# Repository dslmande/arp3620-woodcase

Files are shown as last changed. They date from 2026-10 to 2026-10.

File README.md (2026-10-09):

# ARP 3620 replica — wooden case

Wooden enclosure for a DIY replica of the **ARP 3620** duophonic keyboard (the
keyboard of the ARP 2600P), built around a current **Fatar TP/9S 49-key** keybed
instead of the original ARP key mechanism.

Birch plywood covered in black tolex, with a removable lid. Everything is
generated from one parameter file: 3D model with collision checks, a DXF per
part, renders and a 10-sheet production drawing.

**Status: Rev0.1, design stage — not built yet.** Read the open points below
before cutting.

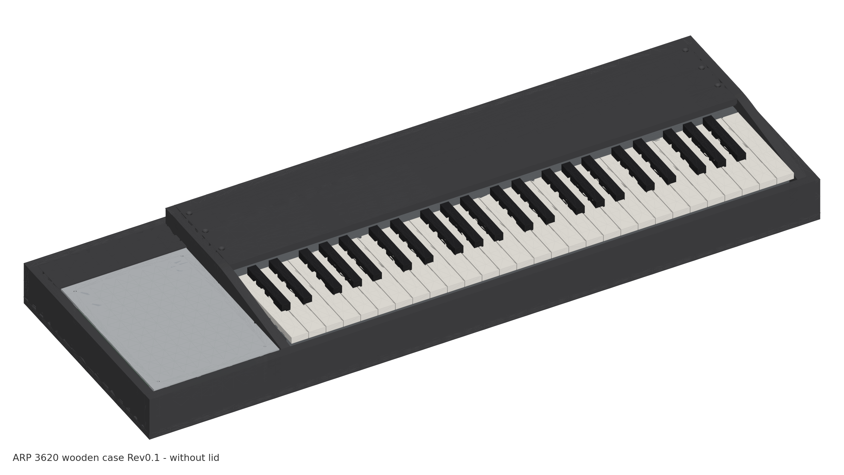
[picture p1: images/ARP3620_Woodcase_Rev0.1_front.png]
Case without lid


| | |
|---|---|
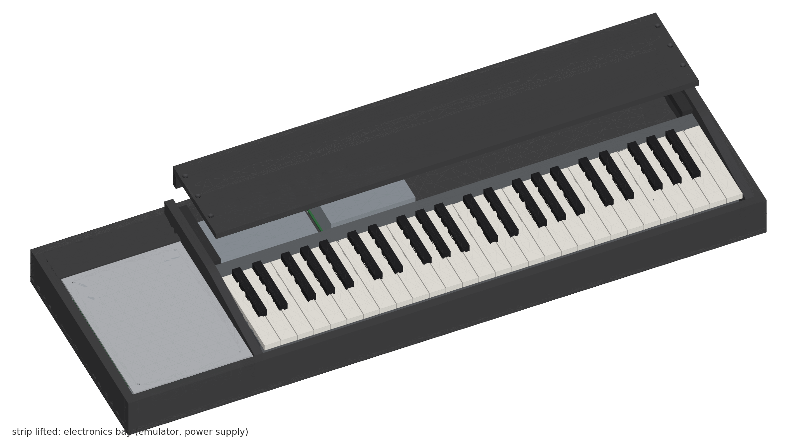
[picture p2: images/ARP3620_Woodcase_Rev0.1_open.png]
Electronics bay
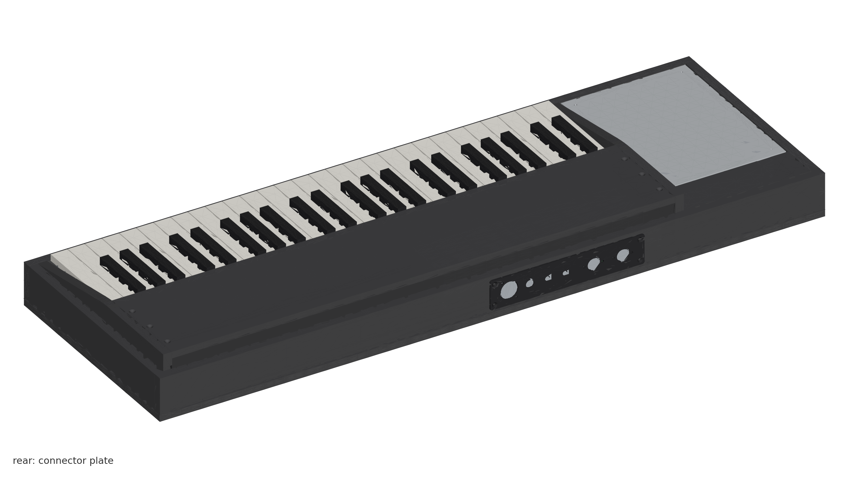
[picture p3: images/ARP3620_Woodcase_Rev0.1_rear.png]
Rear
|  |  |
| Strip lifted: electronics bay | Rear: connector plate |

## Concept

- **Layout as on the original and the 2014 clone:** control panel on the left,
  flush with the walls, keybed on the right between two cheeks, a raised strip
  behind the keys.
- **Heights follow from the keybed.** The keybed stands on two 12 mm risers so
  that the lower edge of the white key fronts sits just above the wall top. This
  leaves 48 mm under the control panel for the 3620 board.
- **Electronics bay behind the keybed**, under the removable strip: bus emulator
  (160 × 110) and power supply board (126 × 80). Cables to the panel section run
  through a notch in the left cheek.
- **Rear connector plate** (aluminium 2 mm) over a window in the rear wall: USB
  (option), DC IN, POWER, SUPPLY 2600/INT, MIDI IN, MIDI OUT. The connection to
  the ARP 2600 (6-pin GX16) sits on the control panel.
- **Lid** sits on the walls and is held by 4 draw latches; 30 mm clear height
  above the walls, 7 mm above the strip.

| | |
|---|---|
| Outside | 911 × 310 mm, walls 59 high, strip 82, with lid 95 (+ feet 12) |
| Material | birch plywood 12 / 9 / 6 mm, black tolex, aluminium rear plate |
| Mass | approx. 5.7 kg wood and plate (lid 1.6 kg), without keybed and electronics |
| Keybed | Fatar TP/9S 49 (683 × 161.5), screwed from below through base and risers |
| Control panel | 170 × 230 × 2 on four M3 standoffs from the base |

## Differences to the original 3620

- **Keys set back behind a front wall.** On the original the white keys reach
  almost to the front edge of the case (a top-view photo in the owner's manual
  shows only a 2–3 mm rim). Here the key fronts sit 15 mm behind the outer face
  (12 mm front wall + 3 mm clearance); the white key tops stand 9.5 mm above the
  wall. Kept on purpose (decision 09.10.2026).
- **Deeper case** (310 mm instead of roughly the panel depth of the original) for
  the electronics bay behind the keybed.

## Files

| Path | Content |
|---|---|
| [`production/ARP3620_Woodcase_Rev0.1_drawing.pdf`](production/ARP3620_Woodcase_Rev0.1_drawing.pdf) | Drawing, A3, 10 sheets: overview, general arrangement, sections, every part with dimensions and hole tables, cut list, hardware, assembly |
| [`production/dxf/`](production/dxf/) | One DXF (R12, mm) per distinct part, seen from its front face. Layers `OUTLINE`, `CUTOUT`, `DRILL`, `CSK_FRONT`, `CSK_BACK` (countersink on the far face), `PILOT`, `ENGRAVE` |
| [`production/ARP3620_Woodcase_Rev0.1.step`](production/ARP3620_Woodcase_Rev0.1.step) | All case parts as solids |
| `model/` | FreeCAD file, assembly STEP with simplified reference bodies (keybed, panel, boards), check report, DXF preview |
| `images/` | Renders |
| `scripts/` | Generator, see below |

## How the data are made

Nothing is drawn by hand. `scripts/params.py` holds every dimension,
`scripts/parts.py` describes each part as a flat outline with holes and
cut-outs. From that:

```bash
scripts/make.sh
```

runs `build.py` (FreeCAD: solids, collision and clearance checks, STEP),
`dxf_out.py` and `dxf_preview.py` (DXF, read back with an independent parser),
`render.py` and `drawing.py`. Needs FreeCAD 1.x (`freecadcmd`) and Python 3 with
matplotlib.

**Checked in the 3D model** (`model/check.txt`): every part is a valid solid,
90 part pairs without collision, and the clearances keybed–cheeks 3, keys–front
wall 3, panel all round 2, lid–strip 7, and electronics to strip, apron and rear
plate parts. Countersinks were verified to open to the intended face.

## Open points (check before cutting)

- **Key front height.** The lower edge of the white key fronts, 39 mm above the
  mounting plane, is scaled from the Fatar drawing. All case heights follow
  from it (`KB_LIP` in `params.py`). Measure it on the real keybed first.
- **Keybed screws.** The feet have 4.5 mm holes; screw type and length still to
  be confirmed on the keybed.
- **Space under the control panel.** The 12 mm board spacer and 25 mm for parts
  and plugs under the 3620 board are estimates. Check them with the built board.
- **Rear plate.** The hole sizes are placeholders until the sockets and
  switches are chosen.
- **Hardware.** Latch type, optional handle and case corners.

## Reference: the 2014 clone

The DIY clone from 2014 (Muffwiggler group buy) used a black MDF case,
915 × 257 mm, with a lid. Its drawings were made for a Kimber Allen keybed and
are **not part of this repository** — they are third-party work and stay with
their author. They are attached to the project page in the wiki:
[ARP 3620 Keyboard Clone](https://diysynth.wiki.dsl-man.de/wiki/spaces/DSO/pages/1146915).
This design takes only the overall concept from them; all dimensions are derived
anew from the Fatar keybed and the panel.

## License

© 2026 Dsl-man.de

Licensed under [Creative Commons Attribution-ShareAlike 4.0 International](LICENSE)
(CC BY-SA 4.0), including the generator scripts. You may build, modify and
redistribute this design, commercially too, as long as you credit the source and
share your changes under the same license.

Not covered by this license: third-party documents referred to above (the 2014
case drawings, the Fatar datasheet), which keep their own rights. The keybed
dimensions used here are taken from the Fatar TP/9S datasheet.

ARP and ARP 3620 are names of ARP Instruments, Inc. This is an independent
DIY project, not affiliated with or endorsed by ARP or its successors.

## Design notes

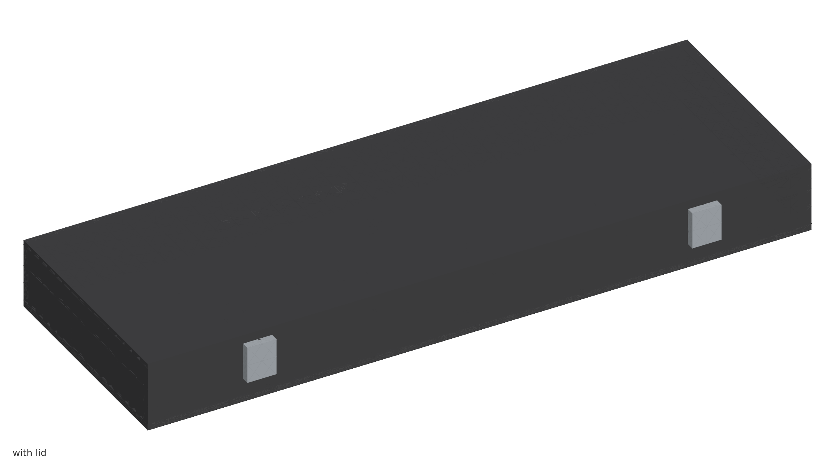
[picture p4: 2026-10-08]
images/ARP3620_Woodcase_Rev0.1_closed.png

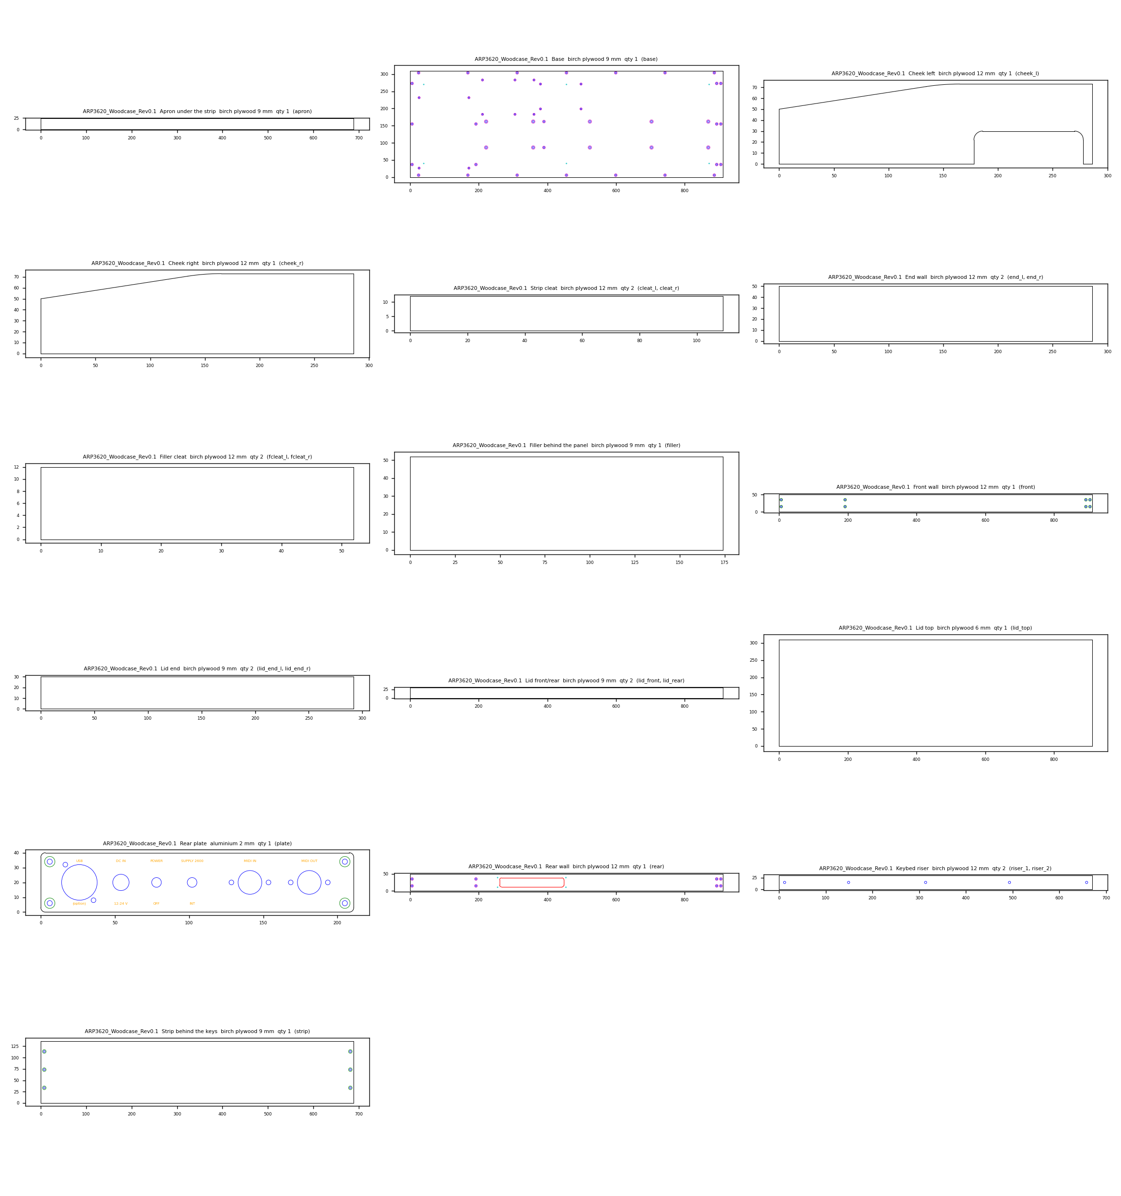
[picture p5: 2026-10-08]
model/dxf_preview.png

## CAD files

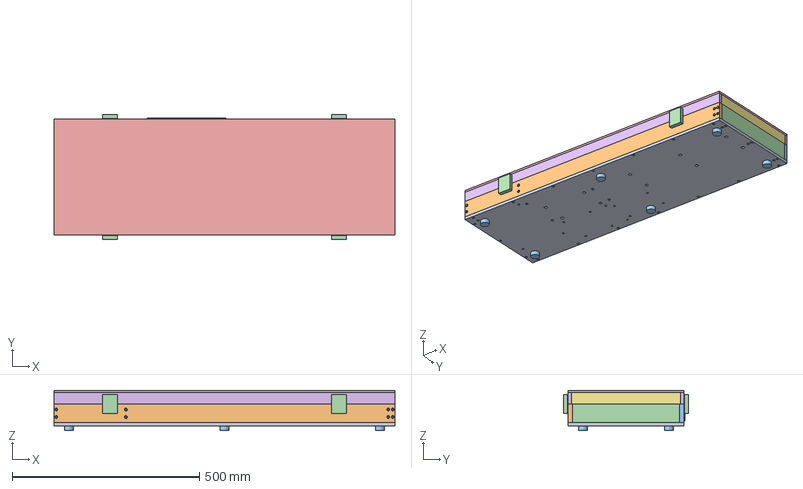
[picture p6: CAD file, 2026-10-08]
model/ARP3620_Woodcase_Rev0.1_assembly.step
911.0 x 334.0 x 107.0 mm
Base
Front wall
Rear wall
End wall
End wall001
Cheek left
Cheek right
Keybed riser
Keybed riser001
Strip behind the keys
Apron under the strip
Strip cleat
Strip cleat001
Filler behind the panel
Filler cleat
Filler cleat001
Lid top
Lid front/rear
Lid front/rear001
Lid end
Lid end001
Rear plate
REF keybed_frame
REF keys_white
REF keys_black
REF panel
REF panel_standoffs
REF board3620
REF board3620_parts
REF panel_jacks
REF emulator
REF emulator_parts
REF emulator_standoffs
REF psu
REF psu_parts
REF psu_standoffs
REF plate_parts
REF feet
REF latches

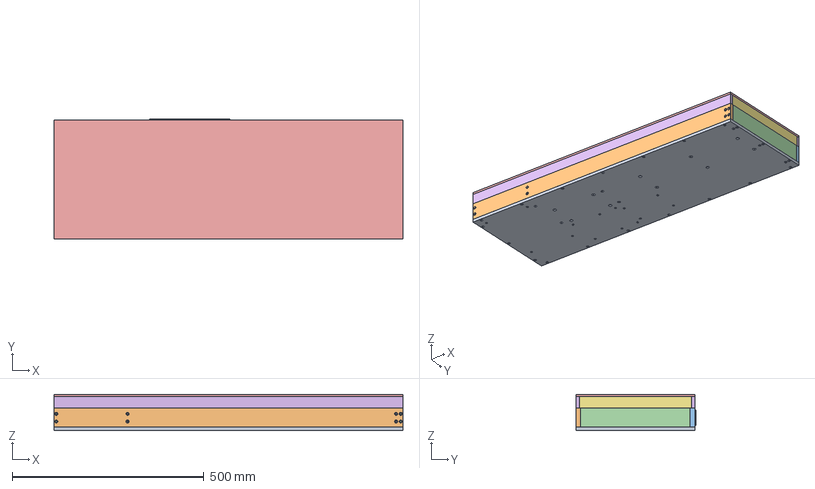
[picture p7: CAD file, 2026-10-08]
production/ARP3620_Woodcase_Rev0.1.step
911.0 x 313.0 x 95.0 mm
Base
Front wall
Rear wall
End wall
End wall001
Cheek left
Cheek right
Keybed riser
Keybed riser001
Strip behind the keys
Apron under the strip
Strip cleat
Strip cleat001
Filler behind the panel
Filler cleat
Filler cleat001
Lid top
Lid front/rear
Lid front/rear001
Lid end
Lid end001
Rear plate

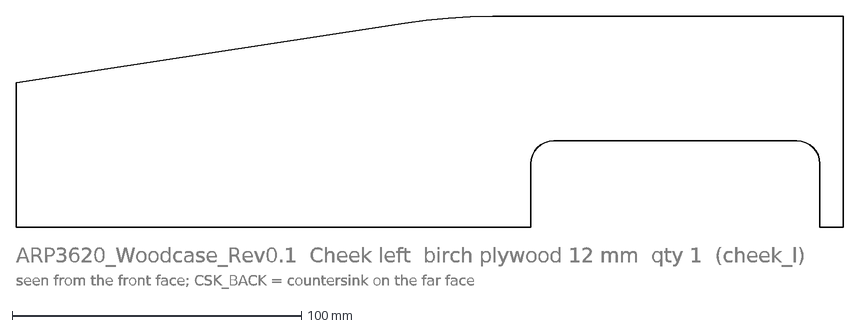
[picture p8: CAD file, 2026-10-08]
production/dxf/ARP3620_Woodcase_Rev0.1_cheek_l.dxf
ARP3620_Woodcase_Rev0.1 Cheek left birch plywood 12 mm qty 1 (cheek_l)
seen from the front face; CSK_BACK = countersink on the far face

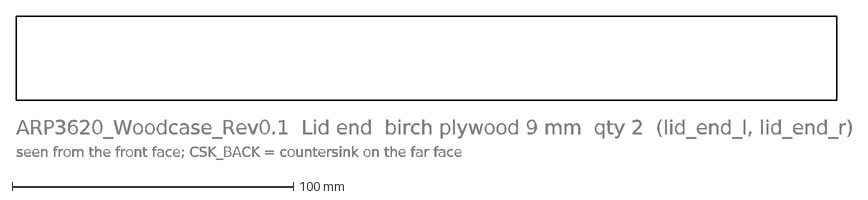
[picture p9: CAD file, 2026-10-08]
production/dxf/ARP3620_Woodcase_Rev0.1_lid_end_l.dxf
ARP3620_Woodcase_Rev0.1 Lid end birch plywood 9 mm qty 2 (lid_end_l, lid_end_r)
seen from the front face; CSK_BACK = countersink on the far face

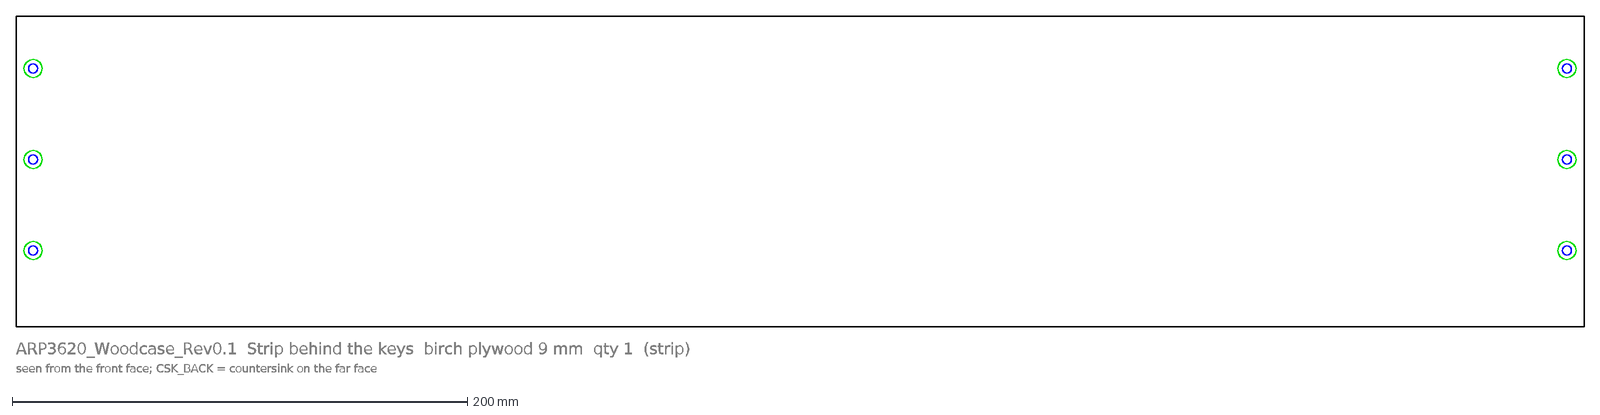
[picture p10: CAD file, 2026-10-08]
production/dxf/ARP3620_Woodcase_Rev0.1_strip.dxf
ARP3620_Woodcase_Rev0.1 Strip behind the keys birch plywood 9 mm qty 1 (strip)
seen from the front face; CSK_BACK = countersink on the far face

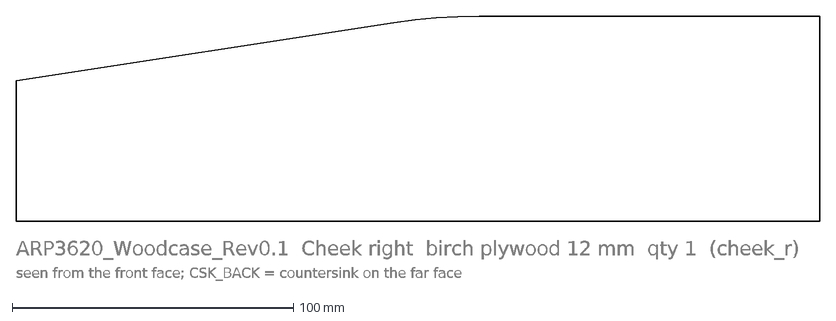
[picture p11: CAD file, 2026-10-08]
production/dxf/ARP3620_Woodcase_Rev0.1_cheek_r.dxf
ARP3620_Woodcase_Rev0.1 Cheek right birch plywood 12 mm qty 1 (cheek_r)
seen from the front face; CSK_BACK = countersink on the far face

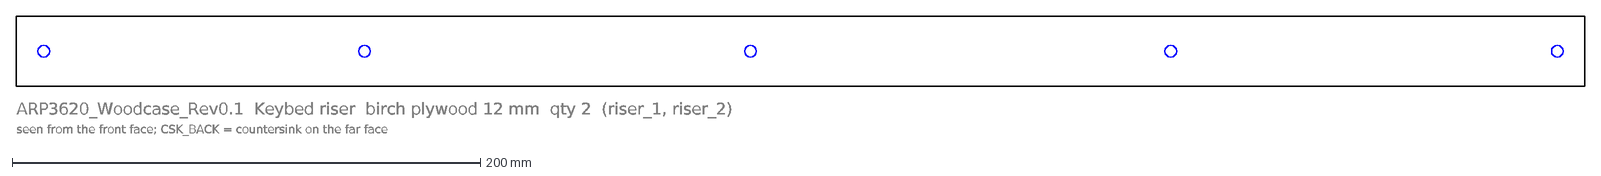
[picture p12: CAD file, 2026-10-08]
production/dxf/ARP3620_Woodcase_Rev0.1_riser_1.dxf
ARP3620_Woodcase_Rev0.1 Keybed riser birch plywood 12 mm qty 2 (riser_1, riser_2)
seen from the front face; CSK_BACK = countersink on the far face

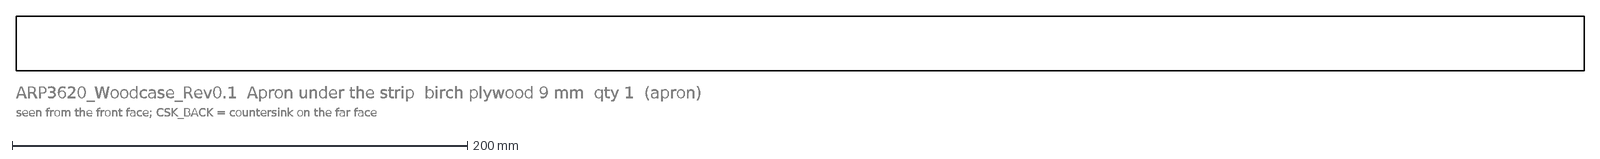
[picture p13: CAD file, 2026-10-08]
production/dxf/ARP3620_Woodcase_Rev0.1_apron.dxf
ARP3620_Woodcase_Rev0.1 Apron under the strip birch plywood 9 mm qty 1 (apron)
seen from the front face; CSK_BACK = countersink on the far face

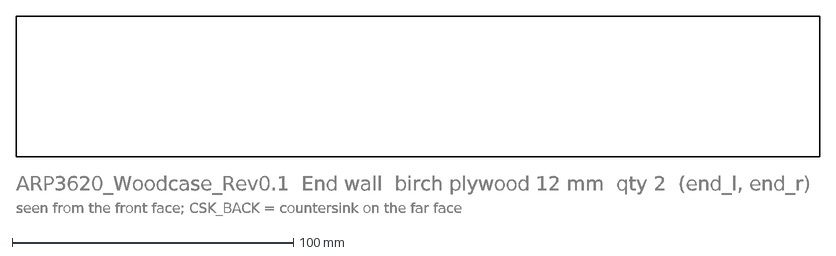
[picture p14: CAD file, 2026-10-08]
production/dxf/ARP3620_Woodcase_Rev0.1_end_l.dxf
ARP3620_Woodcase_Rev0.1 End wall birch plywood 12 mm qty 2 (end_l, end_r)
seen from the front face; CSK_BACK = countersink on the far face

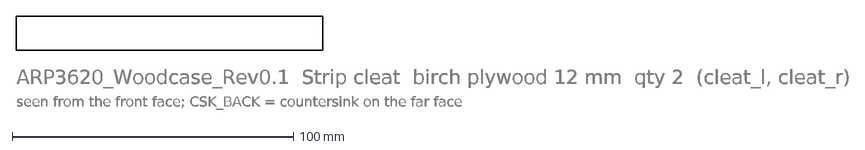
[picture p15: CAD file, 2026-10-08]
production/dxf/ARP3620_Woodcase_Rev0.1_cleat_l.dxf
ARP3620_Woodcase_Rev0.1 Strip cleat birch plywood 12 mm qty 2 (cleat_l, cleat_r)
seen from the front face; CSK_BACK = countersink on the far face

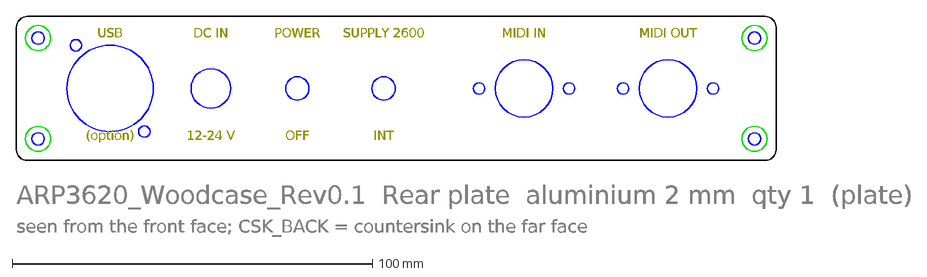
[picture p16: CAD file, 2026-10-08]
production/dxf/ARP3620_Woodcase_Rev0.1_plate.dxf
USB
(option)
DC IN
12-24 V
POWER
OFF
SUPPLY 2600
INT
MIDI IN
MIDI OUT
ARP3620_Woodcase_Rev0.1 Rear plate aluminium 2 mm qty 1 (plate)
seen from the front face; CSK_BACK = countersink on the far face

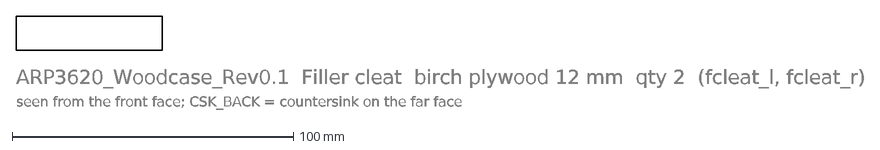
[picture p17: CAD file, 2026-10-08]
production/dxf/ARP3620_Woodcase_Rev0.1_fcleat_l.dxf
ARP3620_Woodcase_Rev0.1 Filler cleat birch plywood 12 mm qty 2 (fcleat_l, fcleat_r)
seen from the front face; CSK_BACK = countersink on the far face

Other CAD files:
model/ARP3620_Woodcase_Rev0.1.FCStd
production/dxf/ARP3620_Woodcase_Rev0.1_lid_front.dxf
production/dxf/ARP3620_Woodcase_Rev0.1_base.dxf
production/dxf/ARP3620_Woodcase_Rev0.1_front.dxf
production/dxf/ARP3620_Woodcase_Rev0.1_rear.dxf
production/dxf/ARP3620_Woodcase_Rev0.1_lid_top.dxf
production/dxf/ARP3620_Woodcase_Rev0.1_filler.dxf

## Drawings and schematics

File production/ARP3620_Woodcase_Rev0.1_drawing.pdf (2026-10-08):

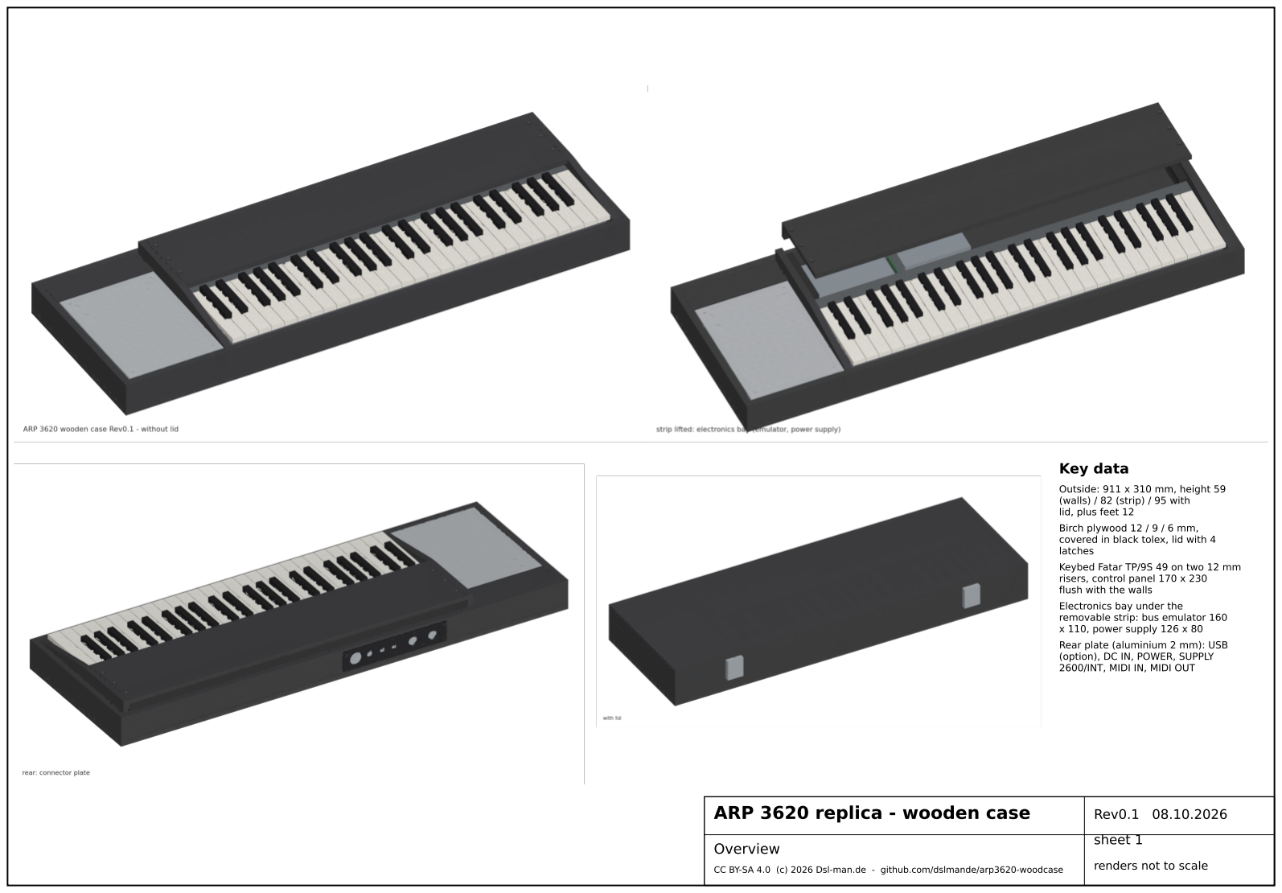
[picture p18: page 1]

ARP 3620 replica - wooden case | Rev0.1 08.10.2026
Overview CC BY-SA 4.0 (c) 2026 Dsl-man.de - github.com/dslmande/arp3620-woodcase | sheet 1 renders not to scale

## Key data

Outside: 911 x 310 mm, height 59 (walls) / 82 (strip) / 95 with
lid, plus feet 12

Birch plywood 12 / 9 / 6 mm, covered in black tolex, lid with 4 latches

Keybed Fatar TP/9S 49 on two 12 mm risers, control panel 170 x 230
flush with the walls

Electronics bay under the
removable strip: bus emulator 160 x 110, power supply 126 x 80

Rear plate (aluminium 2 mm): USB (option), DC IN, POWER, SUPPLY 2600/INT, MIDI IN, MIDI OUT

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

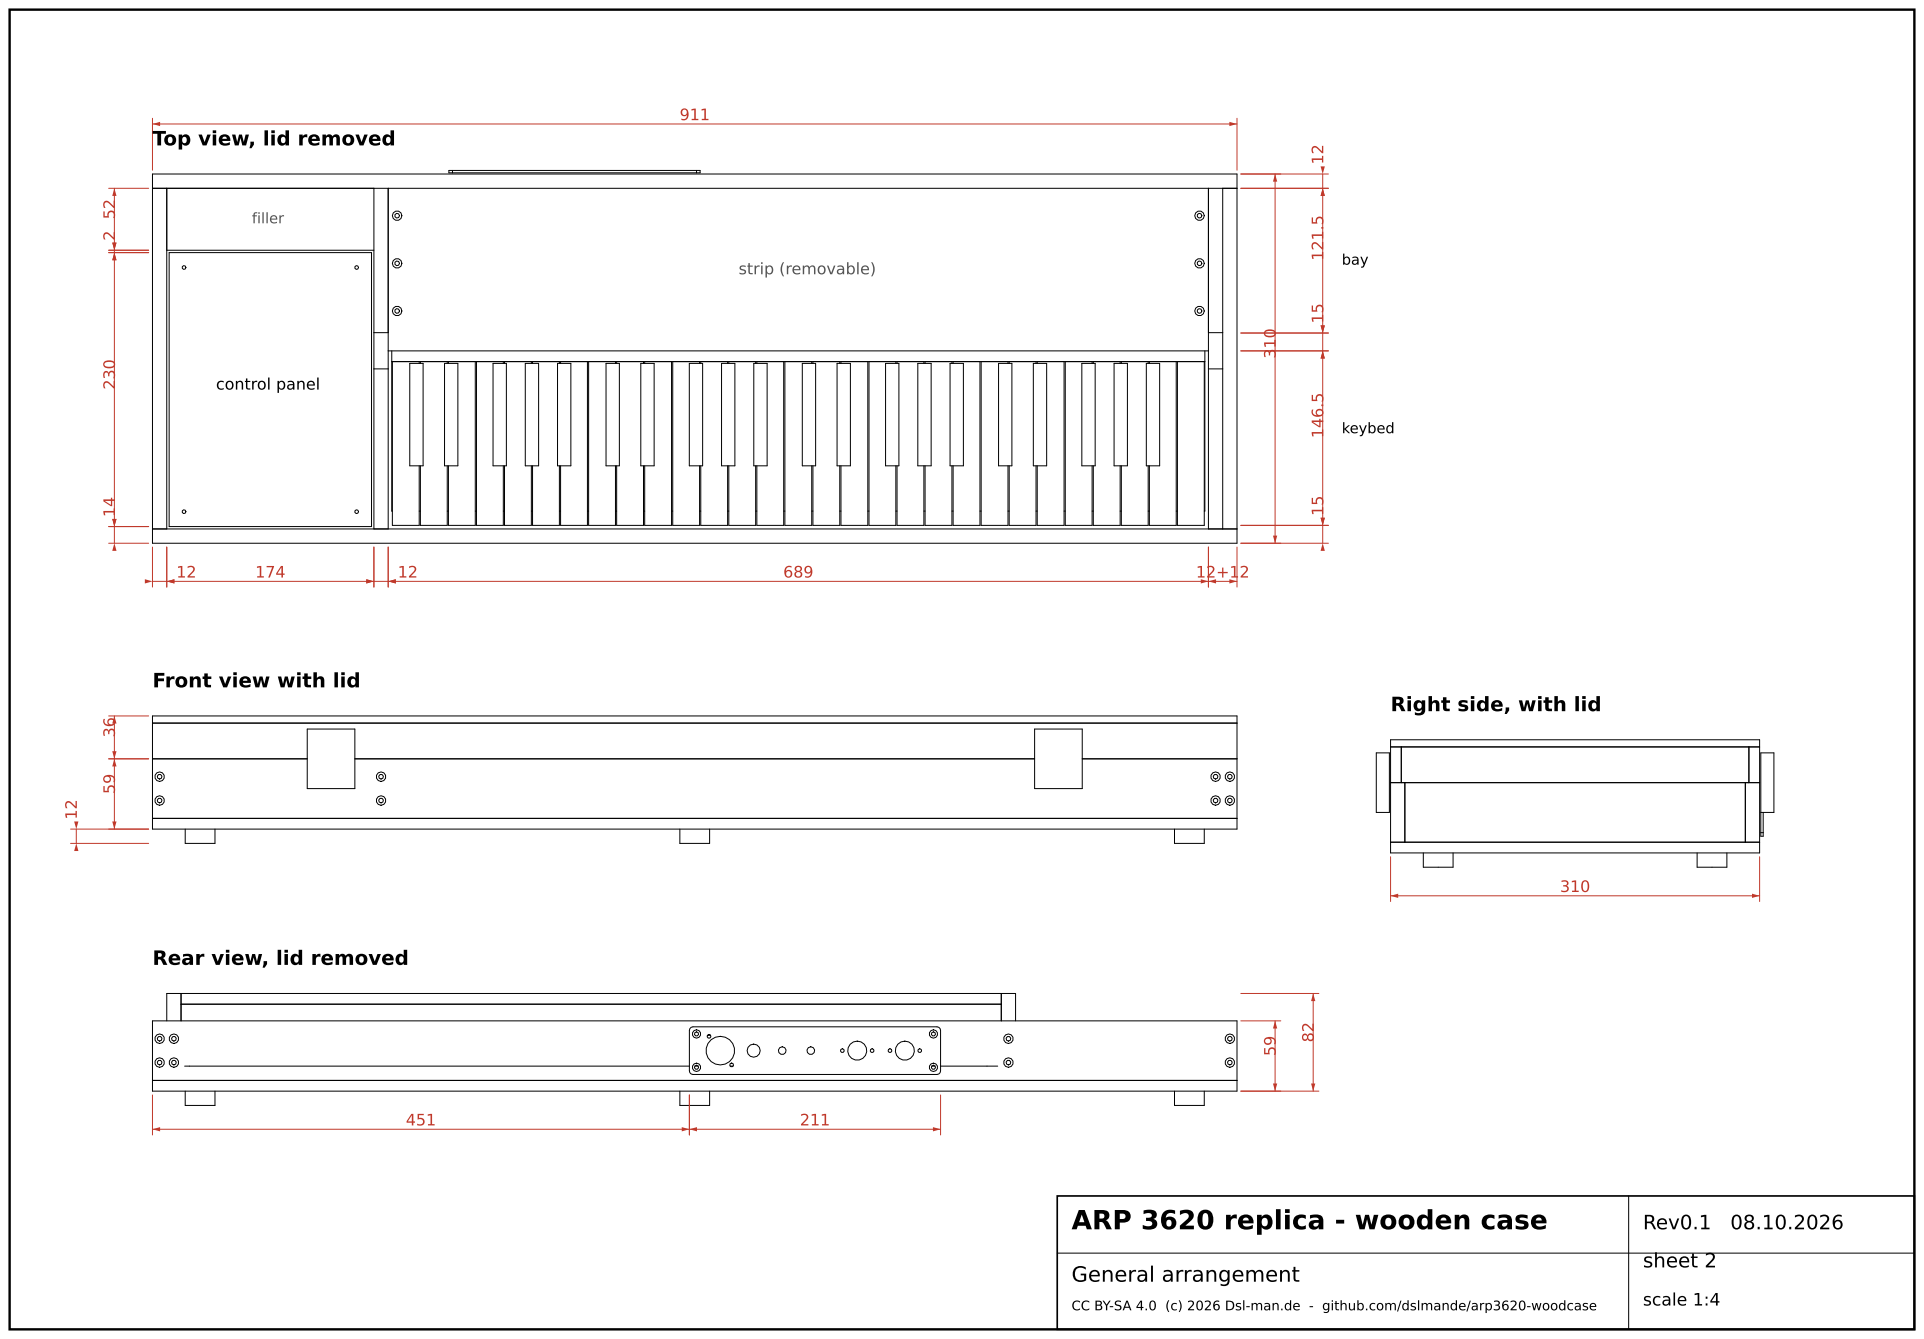
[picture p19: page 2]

## Section A-A at x = 440 (keyboard, power supply), seen from the right

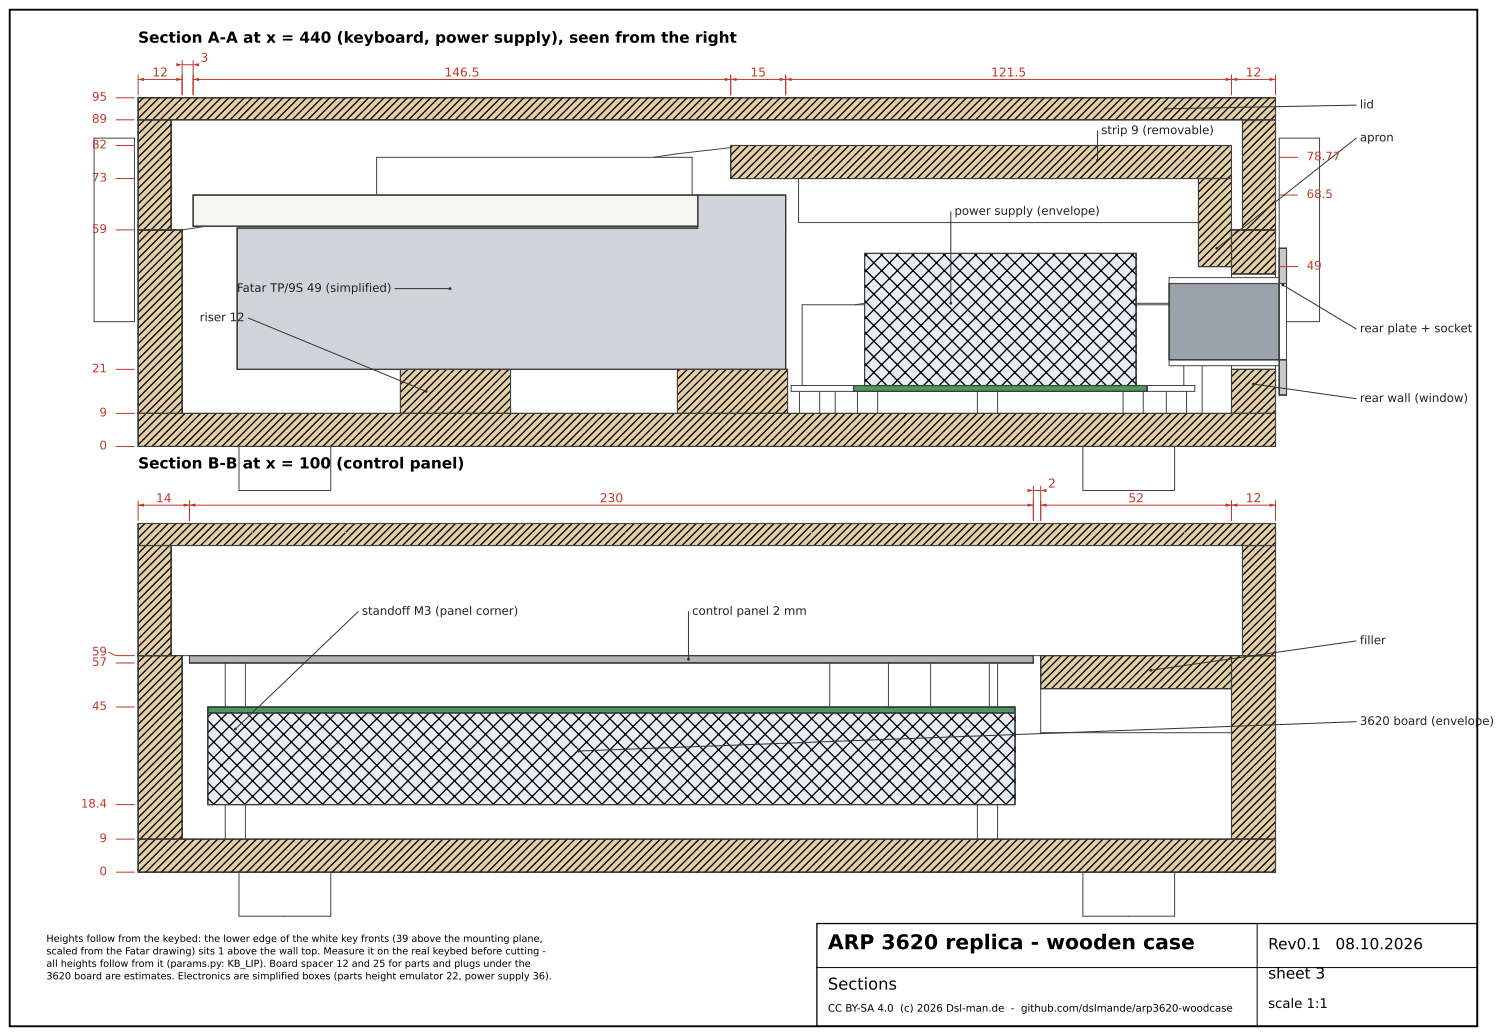
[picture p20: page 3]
Sections; Rev0.1 08.10.2026; scale 1:1; riser 12; strip 9 (removable); apron; lid; Section B-B; (control panel); 3620 board (envelope); filler

power supply (envelope)

Fatar TP/9S 49 (simplified)

rear plate + socket

rear wall (window)

standoff M3 (panel corner)

control panel 2 mm

Heights follow from the keybed: the lower edge of the white key fronts (39 above the mounting plane,
scaled from the Fatar drawing) sits 1 above the wall top. Measure it on the real keybed before cutting -
all heights follow from it (params.py: KB_LIP). Board spacer 12 and 25 for parts and plugs under the
3620 board are estimates. Electronics are simplified boxes (parts height emulator 22, power supply 36).

ARP 3620 replica - wooden case

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

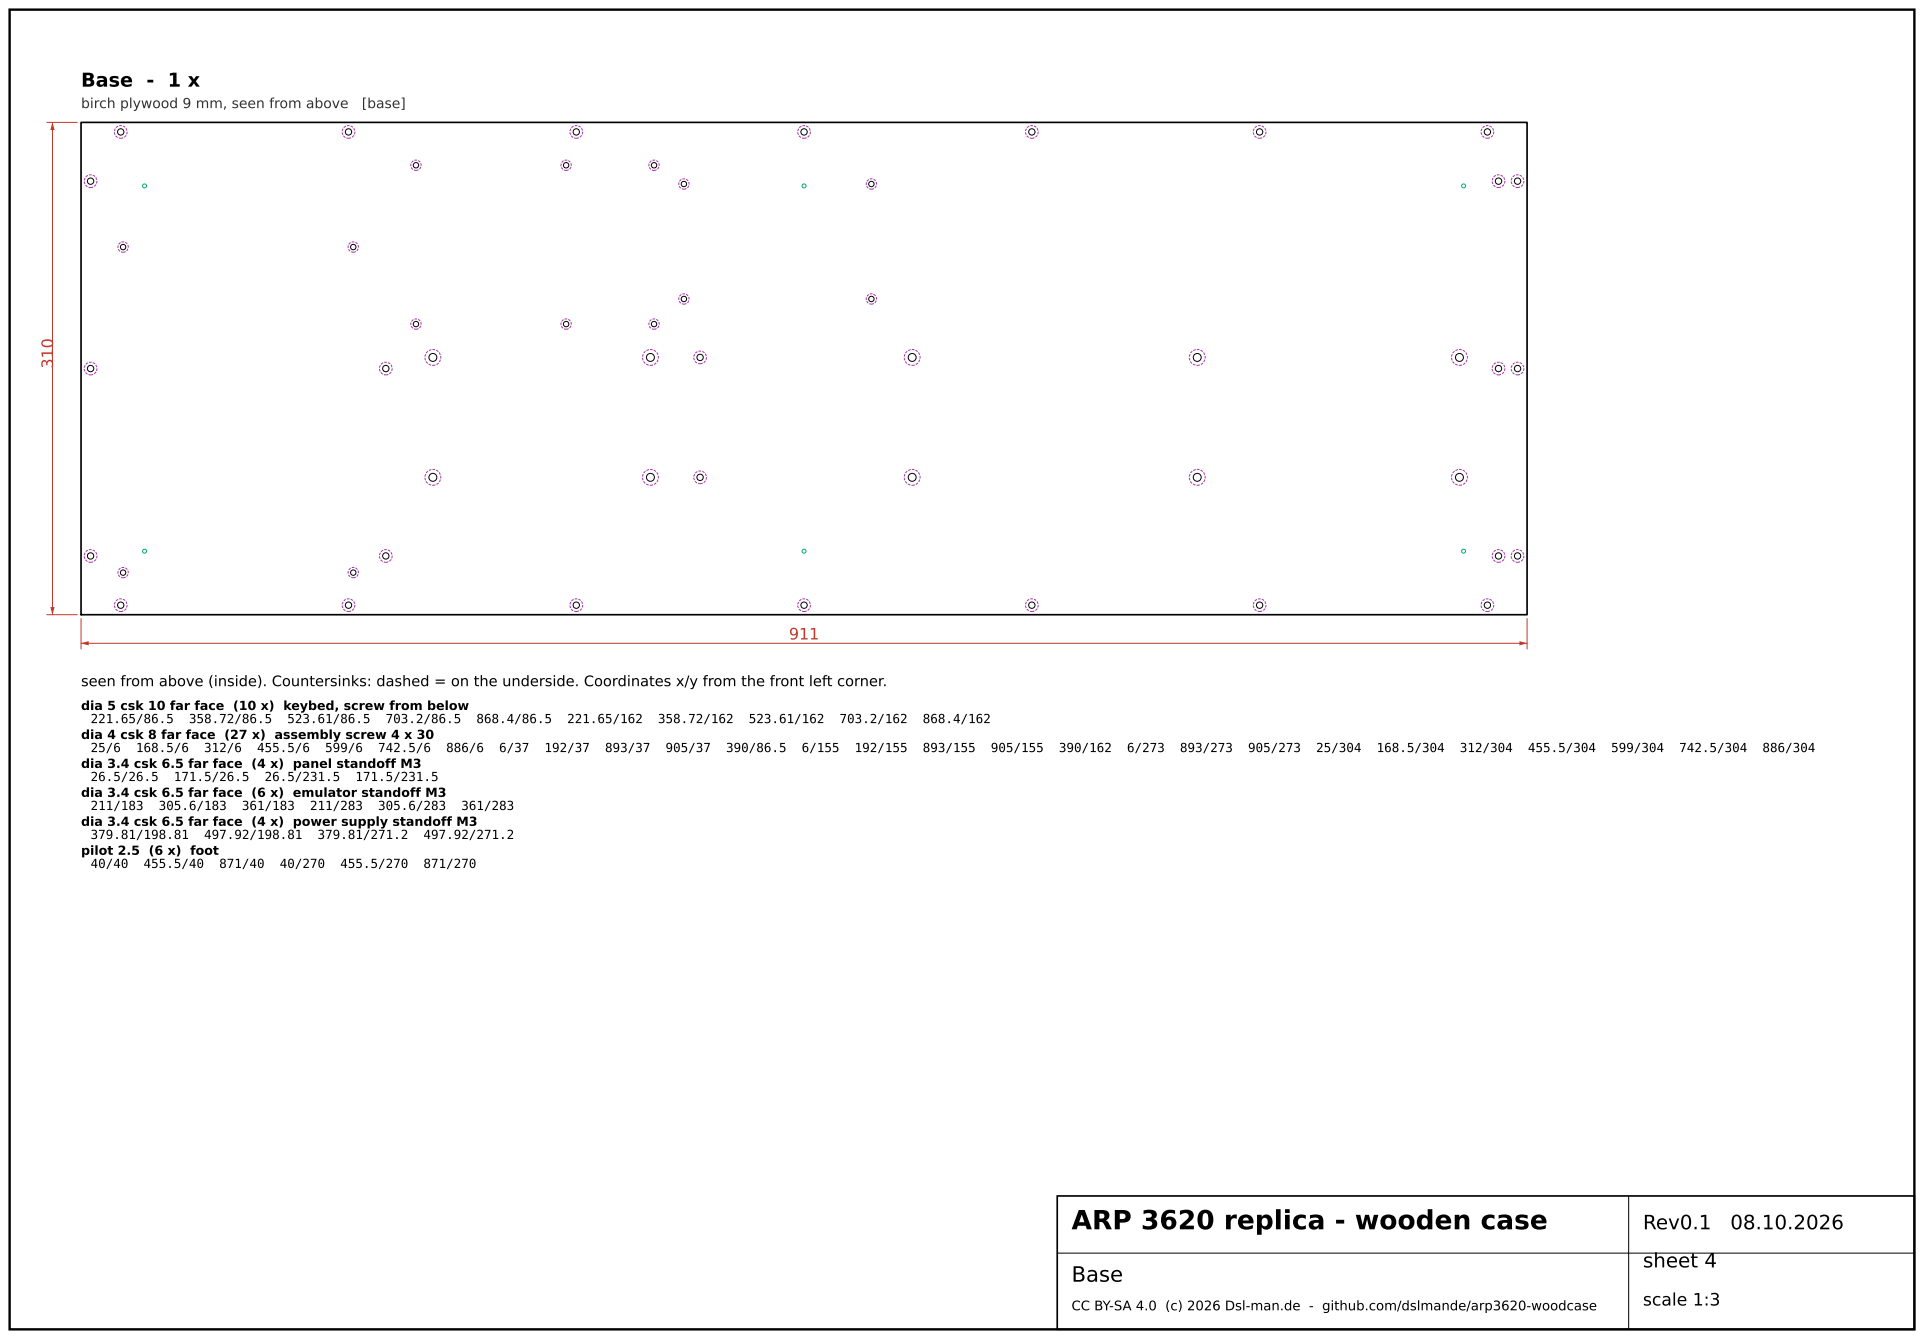
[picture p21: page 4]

## Front wall - 1 x

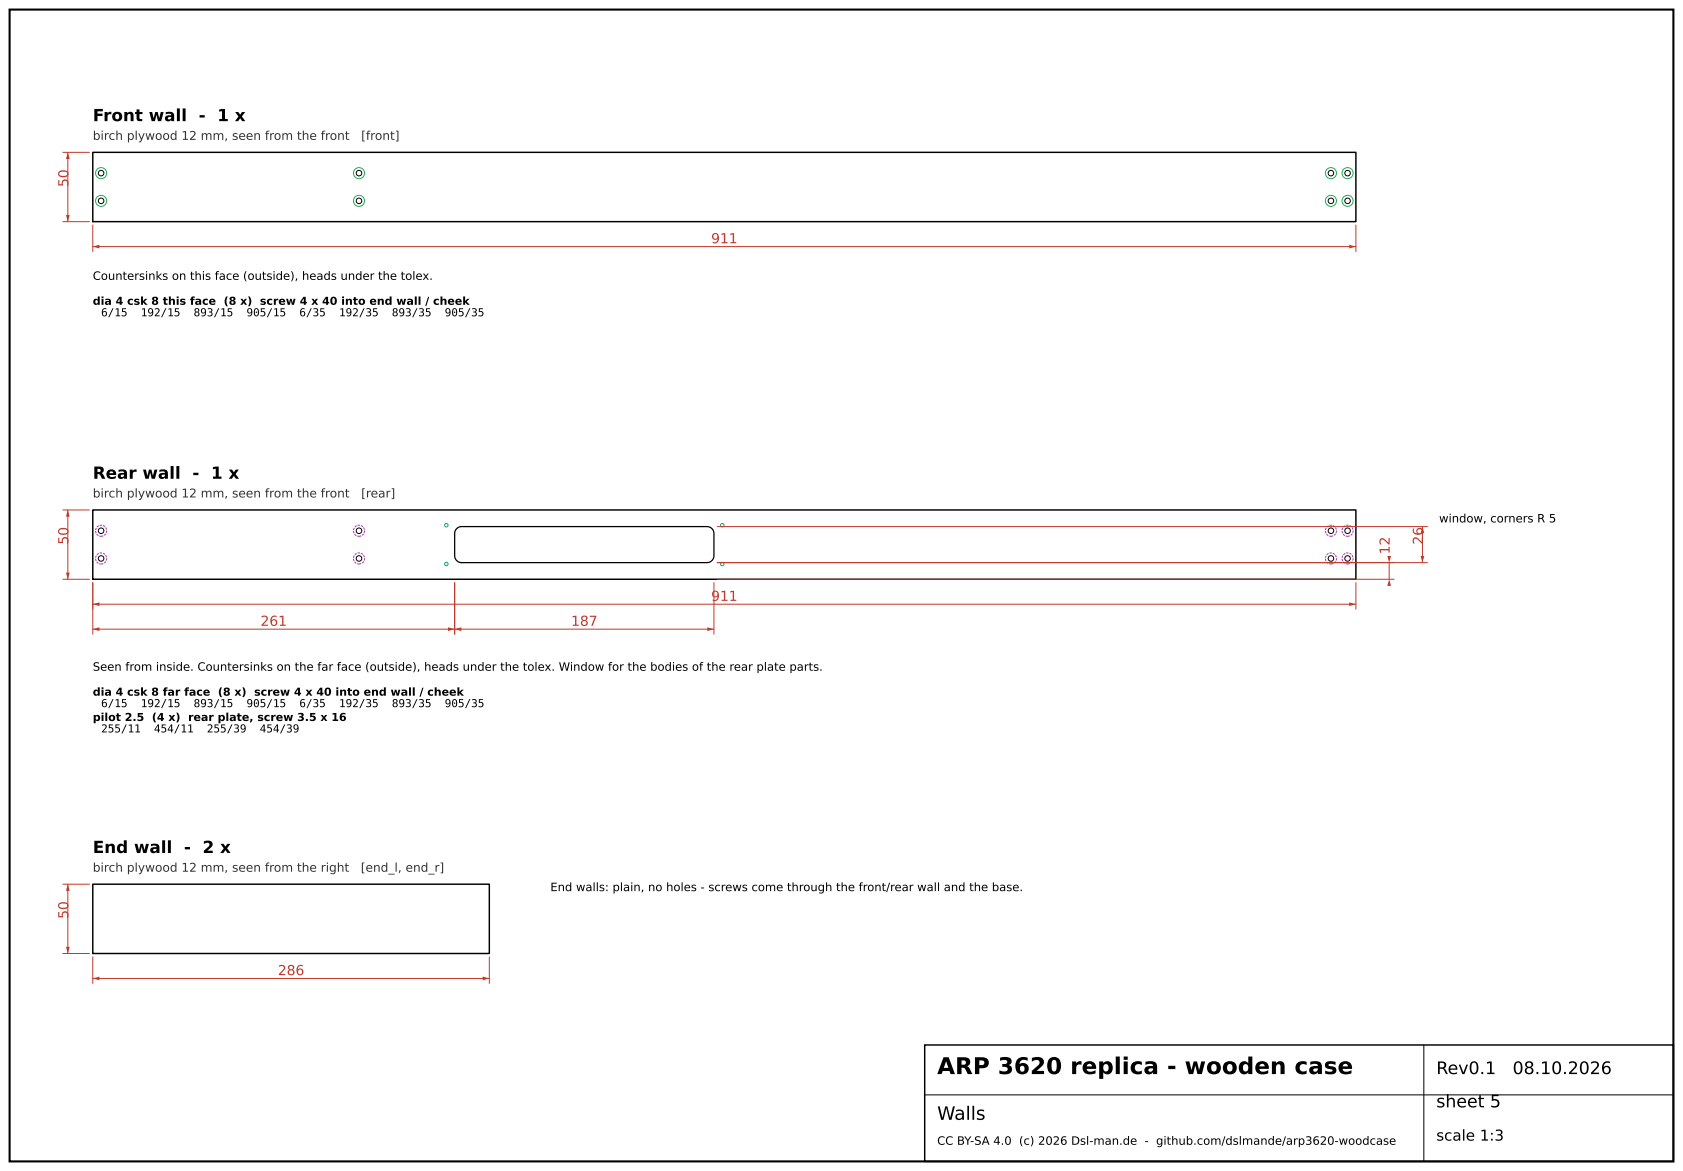
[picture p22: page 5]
Walls; Rev0.1 08.10.2026; Rear wall - 1 x; window, corners R 5; End wall - 2 x

birch plywood 12 mm, seen from the front [front]

Countersinks on this face (outside), heads under the tolex.

dia 4 csk 8 this face (8 x) screw 4 x 40 into end wall / cheek

birch plywood 12 mm, seen from the front [rear]

Seen from inside. Countersinks on the far face (outside), heads under the tolex. Window for the bodies of the rear plate parts.

dia 4 csk 8 far face (8 x) screw 4 x 40 into end wall / cheek
pilot 2.5 (4 x) rear plate, screw 3.5 x 16

birch plywood 12 mm, seen from the right [end_l, end_r]

End walls: plain, no holes - screws come through the front/rear wall and the base.

ARP 3620 replica - wooden case

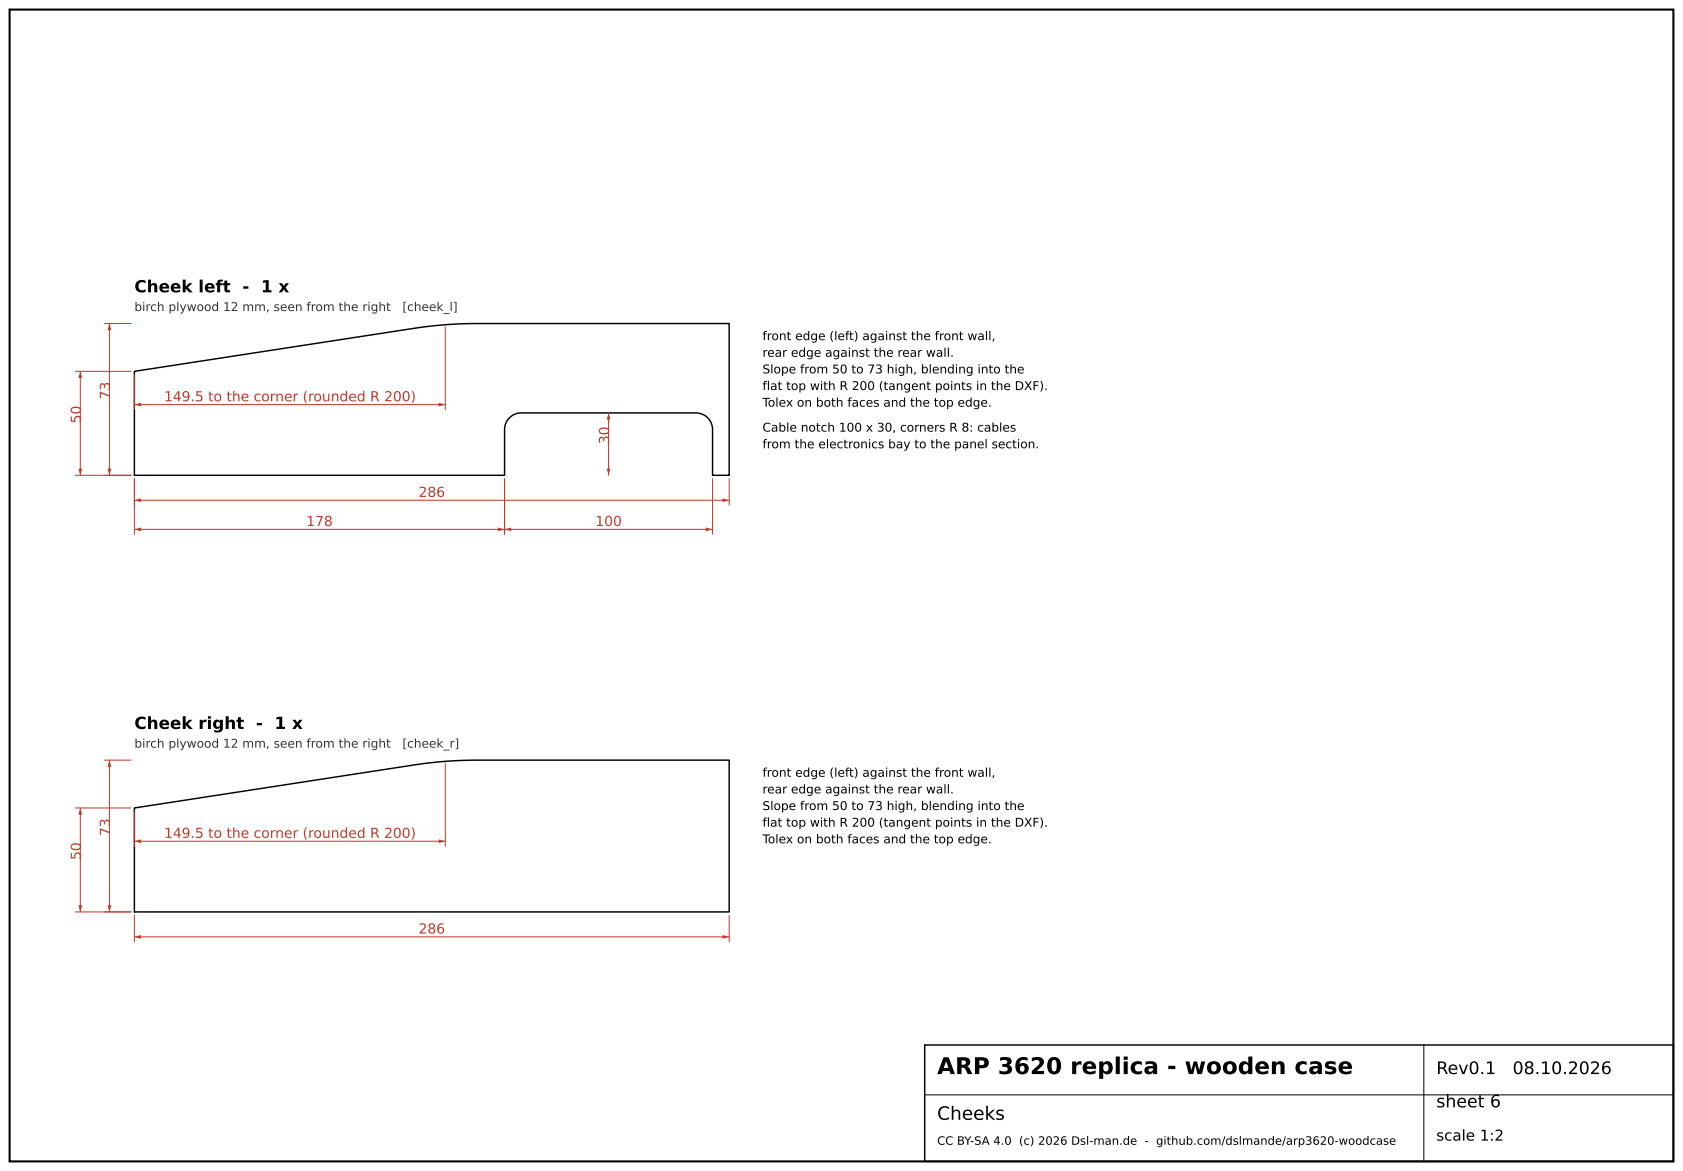
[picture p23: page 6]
Cheeks; Rev0.1 08.10.2026; Cheek left - 1 x; Cheek right - 1 x

birch plywood 12 mm, seen from the right [cheek_l]

front edge (left) against the front wall,
rear edge against the rear wall.
Slope from 50 to 73 high, blending into the
flat top with R 200 (tangent points in the DXF).
Tolex on both faces and the top edge.

149.5 to the corner (rounded R 200)

Cable notch 100 x 30, corners R 8: cables
from the electronics bay to the panel section.

birch plywood 12 mm, seen from the right [cheek_r]

ARP 3620 replica - wooden case

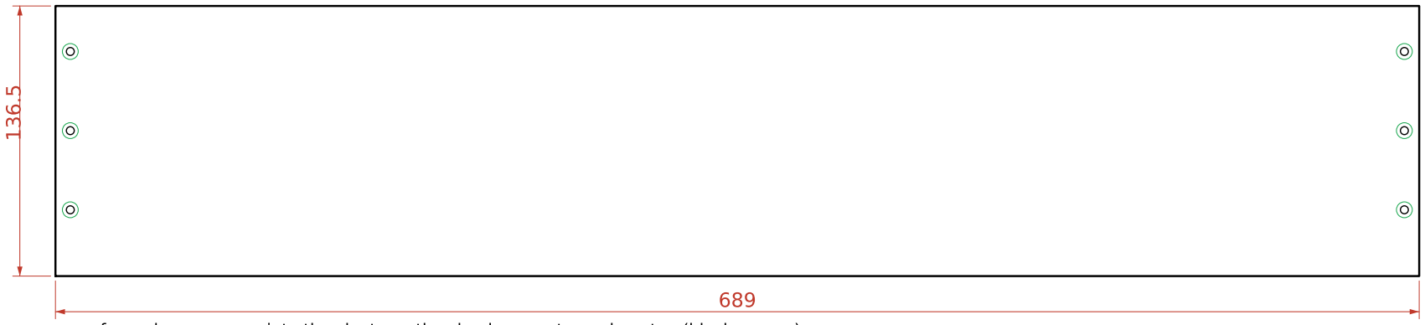
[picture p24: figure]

# ARP 3620 replica - wooden case

## Strip, risers, cleats, filler

## Rev0.1 08.10.2026

### scale 1:3 / 1:2

## Strip behind the keys - 1 x

birch plywood 9 mm, seen from above [strip] dia 4 csk 8 this face (6 x) screw 3.5 x 20 into cleat
7.5/33.5 681.5/33.5 7.5/73.5 681.5/73.5 7.5/113.5 681.5/113.5

seen from above; screws into the cleats on the cheeks, countersunk on top (black screws)

689

24

## Apron under the strip - 1 x

birch plywood 9 mm, seen from the front [apron]

glued under the rear edge of the strip, flush with its rear edge; reaches 10 mm below the wall top

670

30

## Keybed riser - 2 x

birch plywood 12 mm, seen from above [riser_1, riser_2] dia 5 (5 x) keybed screw
11.65/15 148.72/15 313.61/15 493.2/15 658.4/15

two risers along the rows of keybed feet, glued and screwed onto the base

109

12

## Strip cleat - 2 x

birch plywood 12 mm, seen from the right [cleat_l, cleat_r]

glued + 2 screws to the cheek, top 9 below the strip top

52

12

## Filler cleat - 2 x

birch plywood 12 mm, seen from the right [fcleat_l, fcleat_r]

carry the filler (left wall, left cheek)

174

52

## Filler behind the panel - 1 x

birch plywood 9 mm, seen from above [filler]

glued onto the cleats, flush with the wall top
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

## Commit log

2026-10-08 Rev0.1: wooden case for Fatar TP/9S 49 - model, checks, DXF, drawing, renders
    Birch plywood with tolex and lid. Keybed on risers, control panel flush,
    electronics bay under a removable strip, aluminium rear plate.
    Everything generated from scripts/params.py.
    [ARP3620_Woodcase_Rev0.1.FCStd, ARP3620_Woodcase_Rev0.1.step, ARP3620_Woodcase_Rev0.1_apron.dxf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]
2026-10-09 README: differences to the original 3620 (keys set back, deeper case)
2026-11-04 Rev0.2: CNC plug-together joints
    All wooden parts now plug together: finger joints at the wall and lid
    corners, wall tabs into notches in the base and lid top, cheek, filler
    and cleat tabs through slots, apron tabs into the strip. Dogbones R 3.2
    in every inside corner, 0.15 mm play per joint. No screws in the carcass;
    filler cleats dropped, strip cleats plug through the cheeks.
    Model checks: no collisions, all 29 joints in contact, no void in the
    outer shell beyond dogbones and play, every part slides into place in the
    assembly order. Control panel as PCB 1.6 (standoffs 48.4). DXF origin at
    each part's lower left corner, plus one DXF per sheet thickness. New
    drawing sheet for joints and ass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
2026-11-11 Carpenter drawing (no CNC): butt joints, cut list, views, sections, part sketches
    Draft: heights still assume KB_LIP 39 (not measured on the keybed),
    every sheet carries a draft banner until HEIGHTS_CONFIRMED is set.
    Checked against params.py and the Rev0.2 STEP (check_carpenter.txt).
2026-11-11 Rev0.3: keybed on two aluminium Z profiles 20 x 20 x 2 (as on the MS2600 clone)
    The keybed is screwed onto the top flanges from above (rivet nuts M4, keys
    over the holes taken off), the unit is screwed to the base from below into
    rivet nuts in the bottom flanges, which point inwards under the keybed.
    Replaces the 12 mm plywood risers; all heights 8 mm up (walls 67, strip 90,
    with lid 103). KB_LIP 39 confirmed against the Fatar 1:1 drawing (39.3).
    Carpenter drawing Rev0.3-T1 without draft banner; Z profiles listed as
    bought parts, not cut. Rev0.2 outputs removed (tag rev0.2).
2026-11-11 3D fit check: case, Z profiles, keybed and the four ARP 3620 boards from KiCad
    scripts/fit3d: KiCad export of board, panel PCB, emulator and power supply
    (STEP + GLB), placed by their mounting holes; envelopes from the datasheets
    for parts without a 3D model (rocker S1 from E-Switch T331003). FreeCAD
    checks collisions and 15 clearances against the carpenter case with the lid
    closed and the keys pressed: no collision, all clearances kept. Viewer page
    with sections, lid, strip and key states.
2026-11-11 3D fit check: control heights from the datasheets
    PJ301BM body 11.5 + bushing 5.5, PTL45 body 7 + lever 15 swept over the
    travel (no slider caps), Switchcraft 46206/46313 housing, flange and knob
    with throw, RK09D shaft end 25 above the board (was 31.5), MTA-100 header
    + IDC plug, Micro-MaTch insulator 4.0, SI06W8 10.2. Mated cable plugs are
    now added also where KiCad has a header model (emulator J2). Still
    assumed: SB4011 (datasheet not reachable), Micro-MaTch plug height, knob.
    No collisions; controls to the closed lid now 16.2 (S1 rocker).
2026-11-11 3D fit check: board 3620 part height measured, 18 mm
    Patrick measured the tallest parts on board 3620: 18 mm on the part side,
    the WIMA capacitors C2/C4 and the KK headers with crimp housings plugged
    in. Added as envelopes (also on the KK headers of emulator and power
    supply, where the KiCad model shows the header only). Board parts to the
    base now 24.8 (was 27.8), emulator J5 plug to the keybed frame 4.06.
    BOARD_PARTS_BELOW stays 25 as the envelope in the CNC drawing.
2026-11-11 Rev0.4: case without lid
    Patrick, 11.11.2026: no lid. Lid top, lid walls and the four draw
    latches are dropped from params, parts, model, checks, renders, the CNC
    drawing (now 10 sheets), the carpenter drawing Rev0.4-T1 (parts 13-15
    gone) and the 3D fit check (lid clearance check and viewer lid control
    removed). 6 mm plywood no longer needed. Outside 911 x 310 x 90 at the
    strip, mass about 4.3 kg.
    The sections sheet of the CNC drawing is laid out anew: B-B title and
    dimensions no longer run into section A-A, A-A title inside the frame.
    Checks: model/check.txt problems 0, check_carpenter all ok, envelope
    911 x 310 x 90 in both; fit check no collisions, 14/14 clearances.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
2026-11-12 Rev0.5: bus emulator Rev0.3 (160 x 80), MIDI THRU, USB panel-mount cable
    Bus emulator Rev0.3 (board session, branch claude/dreamy-agnesi-fe7d35,
    d7d10e5): 160 x 80 instead of 160 x 110, six M3 standoffs at new
    positions (base holes follow). Same place in the bay (x 206, y 178),
    power supply stays at x 376.
    Rear plate 251 long (was 211) with a third DIN socket MIDI THRU, window
    in the rear wall 227 long. USB now as panel-mount cable Adafruit 3258:
    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
2026-11-13 Rev0.5: bus emulator Rev0.3 now 160 x 86
    Emulator session, 5a89afd: board 86 deep (was 80) so the Pico sits 14 mm
    further in and the USB plug of the panel-mount cable lies over the board
    (socket 15 in front of the rear edge). Standoffs H3/H4/H6 move 6 mm to
    the rear (base holes follow). Board reaches y 264, 34 free to the rear
    wall. Fit check envelope for the plug now over the board, 10-12 high,
    cable bend 15 behind the edge. Rev0.5 is not released yet, so this stays
    in Rev0.5.
    Checks: problems 0, check_carpenter ok; fit check no collisions, all
    clearances ok (USB plug 11.6 to the rear plate parts, 18.9 to the rear
    wall; emulator plugs 4.3 to the keybed).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
2026-11-13 Rev0.5: power supply turned 180 degrees
    Patrick, 2026-11-13: J2-J4 face the emulator, DC terminal J1 front right.
    params.py NT_ROT = 180, base holes from the KiCad holes turned about the
    centre of the place; fit3d places the board turned. New gap checks for the
    power supply against keybed, rear plate parts and the heat sinks: all ok.
2026-11-13 Fit check: emulator J9 now Molex KK 4-pin (emulator 349c09b)
    J9 with plugged housing (envelope 18 high) to the keybed frame 4.05 mm, ok.
2026-11-13 Fit check: emulator Rev0.3 new placement (emulator 10e5f0a)
    J3 POWER IN down at the right edge, J7 one row in, U1 and C1/C2 moved,
    plated mounting holes. No collision, emulator to keybed still 4.05 (J9).
2026-11-13 Rev0.5: emulator standoff H6 3.175 mm to the right (emulator 2335c03)
    Base hole for H6 at emulator (96.52 / 5) instead of (93.345 / 5); all six
    holes checked against the KiCad board. Fit check: no collision, J9 to the
    keybed frame 4.05.
